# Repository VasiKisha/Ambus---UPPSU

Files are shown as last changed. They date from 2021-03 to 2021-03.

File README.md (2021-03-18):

# Ambus---UPPSU

View this project on [CADLAB.io](https://cadlab.io/project/24060). 

## Ambus Commands
|Command |Description |
|:---:|:---:|
| DEV? | get device description |
| FW? | get firmware version |
| SWITCH?  | get HW switch state |
| MODE? | get CC/CV mode |
| VOLT? | get measured output volrage |
| CURR? | get measured output current |
| SETV(?)  | set(get) output voltage |
| SETC(?)  | set(get) output current |
| SWREM(?) | set(get) remote output control |
| OUTPUT?  | get output relay state |
| CALVG(?) | set(get) calibration voltage gain |
| CALVO(?) | set(get) calibration voltage offset |
| CALIG(?) | set(get) calibration current gain |
| CALIO(?) | set(get) calibration current offset |
| SAVE | save settings to EEPROM |
| LOAD | load settings from EEPROM |

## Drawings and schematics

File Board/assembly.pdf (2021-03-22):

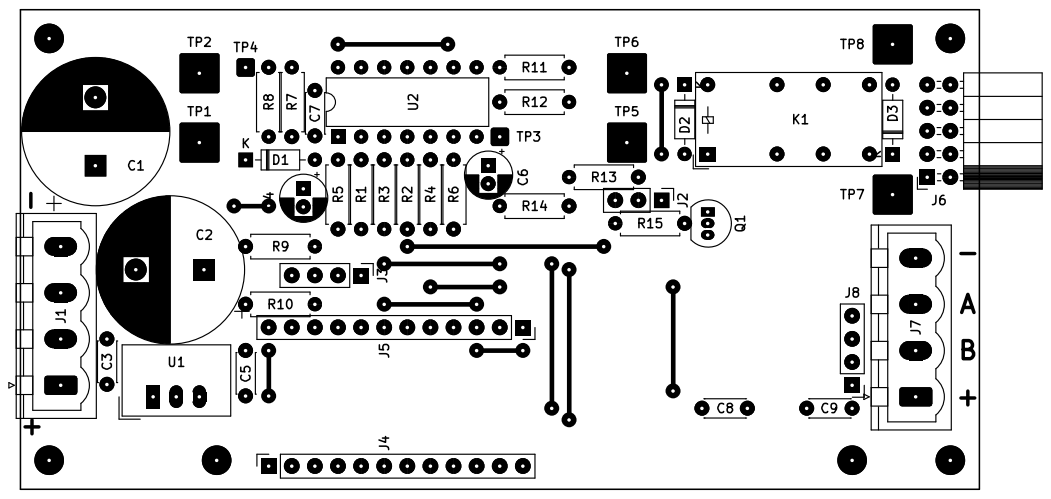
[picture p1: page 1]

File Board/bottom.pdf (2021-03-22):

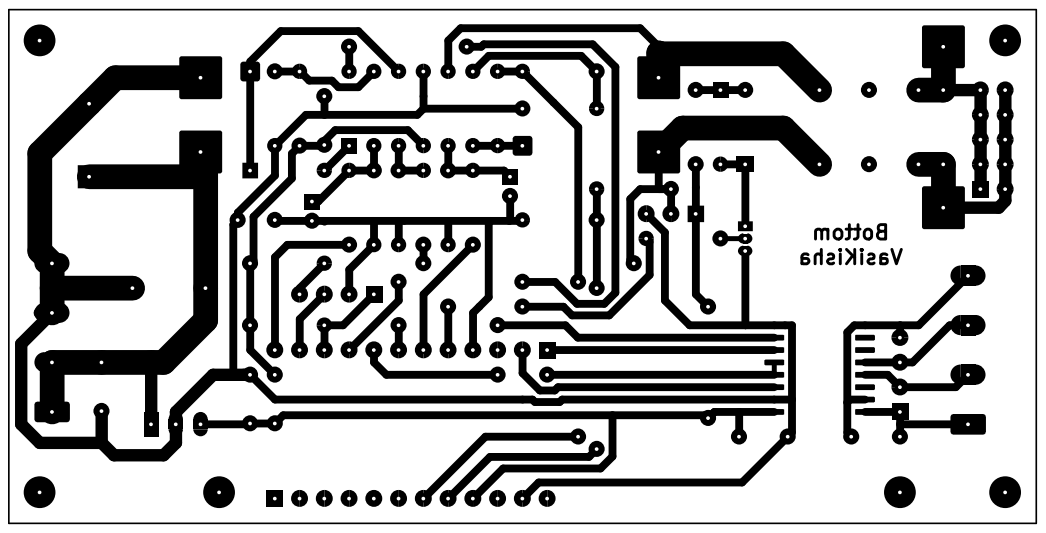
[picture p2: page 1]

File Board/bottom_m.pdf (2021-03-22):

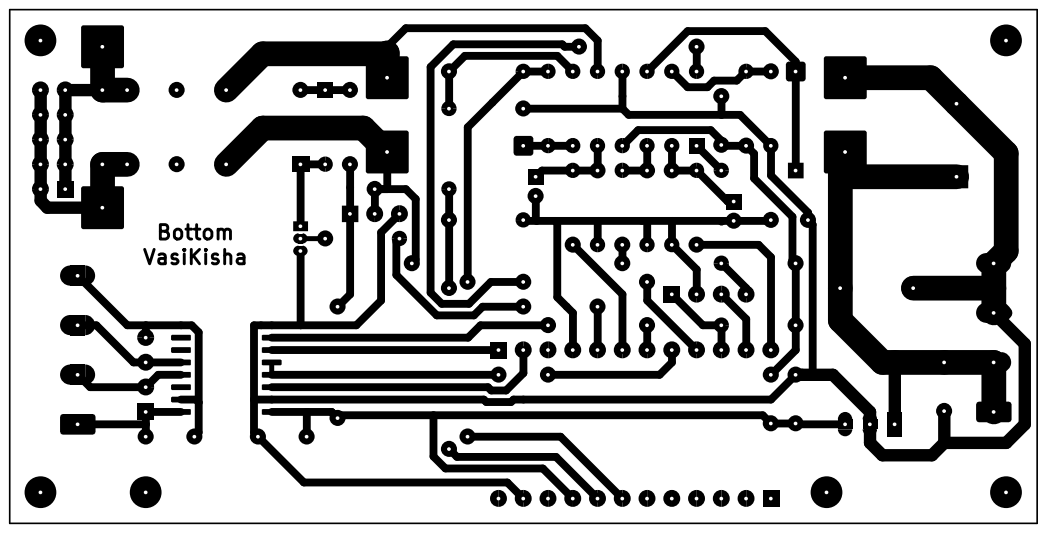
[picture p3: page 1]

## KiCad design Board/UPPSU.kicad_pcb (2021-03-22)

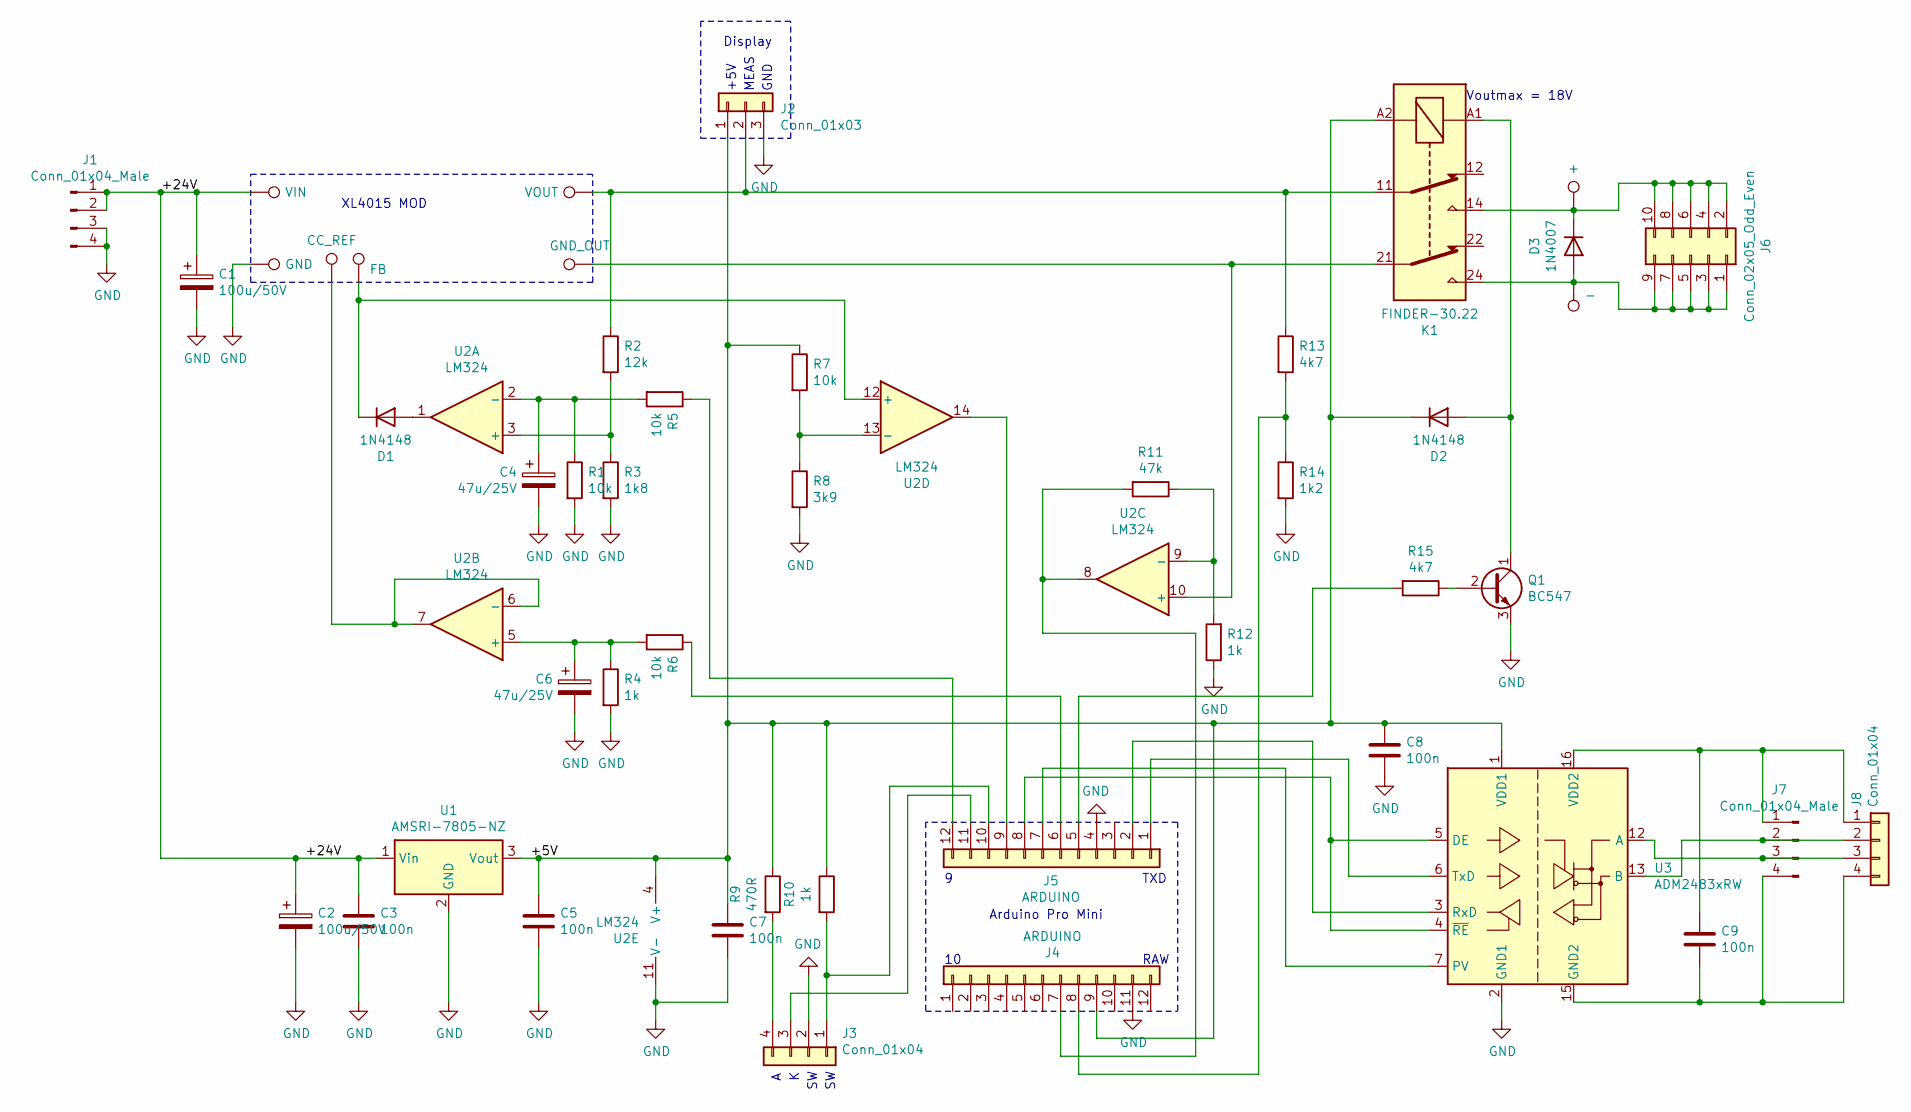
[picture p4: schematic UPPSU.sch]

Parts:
C1, C2: 100u/50V; CP_Radial_D16.0mm_P7.50mm
C3, C5, C7, C8, C9: 100n; C_Disc_D4.3mm_W1.9mm_P5.00mm
C4, C6: 47u/25V; CP_Radial_D5.0mm_P2.00mm
D1, D2: 1N4148; D_DO-35_SOD27_P7.62mm_Horizontal
D3: 1N4007; D_DO-35_SOD27_P7.62mm_Horizontal
J1, J7: Conn_01x04_Male; PhoenixContact_MSTBVA_2,5_4-G-5,08_1x04_P5.08mm_Vertical
J2: Conn_01x03; PinHeader_1x03_P2.54mm_Vertical
J3, J8: Conn_01x04; PinHeader_1x04_P2.54mm_Vertical
J4, J5: ARDUINO; PinSocket_1x12_P2.54mm_Vertical
J6: Conn_02x05_Odd_Even; PinSocket_2x05_P2.54mm_Horizontal
K1: FINDER-30.22; Relay_DPDT_Finder_30.22
Q1: BC547; TO-92_Inline
R1, R5, R6, R7: 10k; R_Axial_DIN0207_L6.3mm_D2.5mm_P7.62mm_Horizontal
R2: 12k; R_Axial_DIN0207_L6.3mm_D2.5mm_P7.62mm_Horizontal
R3: 1k8; R_Axial_DIN0207_L6.3mm_D2.5mm_P7.62mm_Horizontal
R4, R10, R12: 1k; R_Axial_DIN0207_L6.3mm_D2.5mm_P7.62mm_Horizontal
R8: 3k9; R_Axial_DIN0207_L6.3mm_D2.5mm_P7.62mm_Horizontal
R9: 470R; R_Axial_DIN0207_L6.3mm_D2.5mm_P7.62mm_Horizontal
R11: 47k; R_Axial_DIN0207_L6.3mm_D2.5mm_P7.62mm_Horizontal
R13, R15: 4k7; R_Axial_DIN0207_L6.3mm_D2.5mm_P7.62mm_Horizontal
R14: 1k2; R_Axial_DIN0207_L6.3mm_D2.5mm_P7.62mm_Horizontal
TP1: VIN; SolderWire-2.5sqmm_1x01_D2.4mm_OD4.4mm
TP2: GND; SolderWire-2.5sqmm_1x01_D2.4mm_OD4.4mm
TP3: CC_REF; SolderWire-0.25sqmm_1x01_D0.65mm_OD2mm
TP4: FB; SolderWire-0.25sqmm_1x01_D0.65mm_OD2mm
TP5: VOUT; SolderWire-2.5sqmm_1x01_D2.4mm_OD4.4mm
TP6: GND_OUT; SolderWire-2.5sqmm_1x01_D2.4mm_OD4.4mm
TP7: +; SolderWire-2.5sqmm_1x01_D2.4mm_OD4.4mm
TP8: -; SolderWire-2.5sqmm_1x01_D2.4mm_OD4.4mm
U1: AMSRI-7805-NZ; Converter_DCDC_TRACO_TSR-1_THT
U2: LM324; DIP-14_W7.62mm
U3: ADM2483xRW; SOIC-16W_7.5x10.3mm_P1.27mm

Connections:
/+5V: C5.1, C7.1, C8.1, D2.1 (K), J2.1, J4.9, K1.A2, R7.1, R9.1, R10.1, U1.3 (Vout), U2.4 (V+), U3.1 (VDD1)
/+24V: C1.1, C2.1, C3.1, J1.1, J1.2, TP1.1, U1.1 (Vin)
GND: C1.2, C2.2, C3.2, C4.2, C5.2, C6.2, C7.2, C8.2, J1.3, J1.4, J2.3, J3.2, J4.11, J5.4, Q1.3 (E), R1.2, R3.2, R4.2, R8.2, R12.1, R14.2, TP2.1, U1.2 (GND), U2.11 (V-), U3.2 (GND1), U3.8 (GND1)
unnamed: C4.1, R1.1, R5.2, U2.2 (-)
unnamed: C6.1, R4.1, R6.2, U2.5 (+)
unnamed: C9.1, J7.1, J8.1, U3.16 (VDD2)
unnamed: C9.2, J7.4, J8.4, U3.9 (GND2), U3.15 (GND2)
unnamed: D1.1 (K), TP4.1, U2.12 (+)
unnamed: D1.2 (A), U2.1
unnamed: D2.2 (A), K1.A1, Q1.1 (C)
unnamed: D3.1 (K), J6.2, J6.4, J6.6, J6.8, J6.10, K1.14, TP7.1
unnamed: D3.2 (A), J6.1, J6.3, J6.5, J6.7, J6.9, K1.24, TP8.1
unnamed: J2.2, K1.11, R2.1, R13.1, TP5.1
unnamed: J3.1, J5.10, R10.2
unnamed: J3.3, J5.11
unnamed: J3.4, R9.2
unnamed: J4.7, R11.2, U2.8
unnamed: J4.8, R13.2, R14.1
unnamed: J5.1, U3.6 (TxD)
unnamed: J5.2, U3.3 (RxD)
unnamed: J5.5, R15.2
unnamed: J5.6, R6.1
unnamed: J5.7, U3.7 (PV)
unnamed: J5.8, U3.4 (~RE), U3.5 (DE)
unnamed: J5.9, U2.14
unnamed: J5.12, R5.1
unnamed: J7.2, J8.2, U3.13 (B)
unnamed: J7.3, J8.3, U3.12 (A)
unnamed: K1.21, TP6.1, U2.10 (+)
unnamed: Q1.2 (B), R15.1
unnamed: R2.2, R3.1, U2.3 (+)
unnamed: R7.2, R8.1, U2.13 (-)
unnamed: R11.1, R12.2, U2.9 (-)
unnamed: TP3.1, U2.6 (-), U2.7

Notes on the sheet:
XL4015 MOD
Arduino Pro Mini
Display
Voutmax = 18V
RAW
TXD
+5V
MEAS
GND

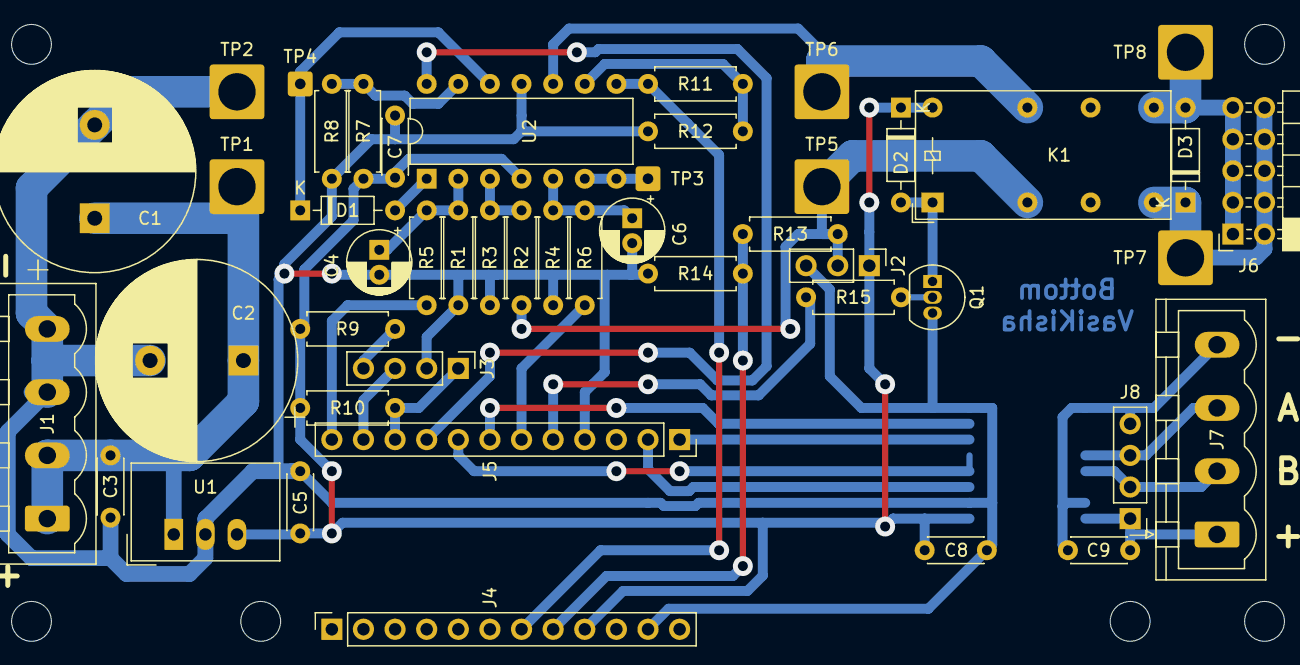
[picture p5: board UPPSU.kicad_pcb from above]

Board: 2 copper layers, 48 parts (1 on the bottom side), 34 nets.

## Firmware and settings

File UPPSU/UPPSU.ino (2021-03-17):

//Copyright (c) 2020 VasiKisha
//All rights reserved.

//This source code is licensed under the MIT-style license found in the
//LICENSE file in the root directory of this source tree. 

//Device description
#define DEVICE "UPPSU"
//Firmware version
#define FIRMWARE "1.0"

//Commands
//DEV?
//FW?
//SWITCH?
//MODE?
//VOLT?
//CURR?
//SETV(?)
//SETC(?)
//SWREM(?)
//OUTPUT?
//CALVG(?)
//CALVO(?)
//CALIG(?)
//CALIO(?)
//SAVE
//LOAD

#include "ambus.h"
#include "EEPROM.h"

#define SWITCH 13   //HW switch
#define LED 12      //LED indicator
#define CCMODE 9    //CC mode = true
#define CVREF 11    //voltage control
#define CCREF 10    //current control
#define VREAD A0    //voltage measure
#define CREAD A1    //current measure

#define MAXVREAD    24.58333    //(Rh = 4k7, Rl = 1k2)
#define MAXCREAD    2.08333     //(Rs = 50mR, A = 48)
#define MAXVSET     19.16666    //(Rh = 12k, Rl = 1k8)
#define MAXCSET     9.09090     //(Rs = 50mR, A = 11)

struct Read
{
    bool switchHW;
    bool switchRem;
    bool ccMode;
    int voltage;
    int current;
};

struct Set
{
    bool led;
    bool output;
    int ccRef;
    int cvRef;
};

struct Timer
{
    int t10;
    int t1000;
    int t300;
};

struct Settings
{
    float vGain;
    int vOffset;
    float iGain;
    int iOffset;
    char myAddress[8];
};

struct Uppsu
{
    Set set;
    Read read;
    Timer timer;
    Settings settings;
}uppsu;

unsigned long previousMillis = 0;

AMBUS ambus("UPPSU", 5);

void setup()
{
    pinMode(CCMODE, INPUT);
    pinMode(SWITCH, INPUT);
    pinMode(LED, OUTPUT);
    pinMode(CVREF, OUTPUT);
    pinMode(CCREF, OUTPUT);
    analogReference(DEFAULT);
    
    EEPROM.get(0, uppsu.settings);
    if (uppsu.settings.myAddress[0] != '\xff') ambus.changeAddress(uppsu.settings.myAddress);
    uppsu.read.switchRem = true;
    Measure();

    Serial.begin(115200);
    uppsu.timer.t10 = 10;
    uppsu.timer.t1000 = 1000;
    uppsu.timer.t300 = 300;
}

void loop()
{
    unsigned long currentMillis = millis();
    if (currentMillis - previousMillis)
    {
        previousMillis = currentMillis;

        if (!uppsu.timer.t300--)
        {
            uppsu.timer.t300 = 300;
            Measure();
            Control();
            
        }

        if (!uppsu.timer.t1000--)
        {

        }       
    }

    if (ambus.dataReceived())
    {
        if (ambus.getCommand() == "DEV?")
        {
            ambus.acknowledge(DEVICE);
        }
        else if (ambus.getCommand() == "FW?")
        {
            ambus.acknowledge(FIRMWARE);
        }
        else if (ambus.getCommand() == "SWITCH?")
        {
            if (uppsu.read.switchHW)
                ambus.acknowledge("ON");
            else
                ambus.acknowledge("OFF");
        }
        else if (ambus.getCommand() == "MODE?")
        {
            if (uppsu.read.ccMode)
                ambus.acknowledge("CC");
            else
                ambus.acknowledge("CV");
        }
        else if (ambus.getCommand() == "VOLT?")
        {
            ambus.acknowledge(String(MAXVREAD * uppsu.read.voltage / 1023.0, 2));
        }
        else if (ambus.getCommand() == "CURR?")
        {
            ambus.acknowledge(String(MAXCREAD * uppsu.read.current / 1023.0, 2));
        }
        else if (ambus.getCommand() == "SETV")
        {
            String temp = ambus.getData();
            uppsu.set.cvRef = 255 * temp.toDouble() / MAXVSET;
            if (uppsu.set.cvRef > 255) uppsu.set.cvRef = 255;
            if (uppsu.set.cvRef < 0) uppsu.set.cvRef = 0;
            ambus.acknowledge(String(MAXVSET * uppsu.set.cvRef / 255, 2));
        }
        else if (ambus.getCommand() == "SETV?")
        {
            ambus.acknowledge(String(MAXVSET * uppsu.set.cvRef / 255, 2));
        }
        else if (ambus.getCommand() == "SETC")
        {
            String temp = ambus.getData();
            uppsu.set.ccRef = 255 * temp.toDouble() / MAXCSET;
            if (uppsu.set.ccRef > 255) uppsu.set.ccRef = 255;
            if (uppsu.set.ccRef < 0) uppsu.set.ccRef = 0;
            ambus.acknowledge(String(MAXCSET * uppsu.set.ccRef / 255, 2));
        }
        else if (ambus.getCommand() == "SETC?")
        {
            ambus.acknowledge(String(MAXCSET * uppsu.set.ccRef / 255, 2));
        }
        else if (ambus.getCommand() == "SWREM")
        {
            String temp = ambus.getData();
            if (temp == "ON")
            {
                uppsu.read.switchRem = true;
                ambus.acknowledge(temp);
            }
            else if (temp == "OFF")
            {
                uppsu.read.switchRem = false;
                ambus.acknowledge(temp);
            }
        }
        else if (ambus.getCommand() == "SWREM?")
        {
            if (uppsu.read.switchRem)
                ambus.acknowledge("ON");
            else
                ambus.acknowledge("OFF");
        }
        else if (ambus.getCommand() == "OUTPUT?")
        {
            if (uppsu.set.output)
                ambus.acknowledge("ON");
            else
                ambus.acknowledge("OFF");
        }
        else if (ambus.getCommand() == "CALVG")
        {
            String temp = ambus.getData();
            uppsu.settings.vGain = temp.toFloat();
            ambus.acknowledge(String(uppsu.settings.vGain, 2));
        }
        else if (ambus.getCommand() == "CALVG?")
        {
            ambus.acknowledge(String(uppsu.settings.vGain, 2));
        }
        else if (ambus.getCommand() == "CALVO")
        {
            String temp = ambus.getData();
            uppsu.settings.vOffset = temp.toInt();
            ambus.acknowledge(String(uppsu.settings.vOffset));
        }
        else if (ambus.getCommand() == "CALVO?")
        {
            ambus.acknowledge(String(uppsu.settings.vOffset));
        }
        else if (ambus.getCommand() == "CALIG")
        {
            String temp = ambus.getData();
            uppsu.settings.iGain = temp.toFloat();
            ambus.acknowledge(String(uppsu.settings.iGain, 2));
        }
        else if (ambus.getCommand() == "CALIG?")
        {
            ambus.acknowledge(String(uppsu.settings.iGain, 2));
        }
        else if (ambus.getCommand() == "CALIO")
        {
            String temp = ambus.getData();
            uppsu.settings.iOffset = temp.toInt();
            ambus.acknowledge(String(uppsu.settings.iOffset));
        }
        else if (ambus.getCommand() == "CALIO?")
        {
            ambus.acknowledge(String(uppsu.settings.iOffset));
        }
        else if (ambus.getCommand() == "SAVE")
        {
            strcpy(uppsu.settings.myAddress, ambus.myAddress().c_str());
            EEPROM.put(0, uppsu.settings);
            ambus.acknowledge("EEPROM Saved");
        }
        else if (ambus.getCommand() == "LOAD")
        {
            EEPROM.get(0, uppsu.settings);
            ambus.changeAddress(uppsu.settings.myAddress);
            ambus.acknowledge("EEPROM Loaded");
        }
    }
}

void Measure()
{
    uppsu.read.switchHW = digitalRead(SWITCH);
    uppsu.read.ccMode = digitalRead(CCMODE);
    uppsu.read.voltage = analogRead(VREAD);
    uppsu.read.current = analogRead(CREAD);
}

void Control()
{
    if (uppsu.read.switchHW && uppsu.read.switchRem)
    {
        uppsu.set.output = true;
        uppsu.set.led = true;
    }
    else
    {
        uppsu.set.output = false;
        uppsu.set.led = false;
    }

    if (uppsu.set.led) digitalWrite(LED, HIGH);
    else digitalWrite(LED, LOW);

    int calValue = uppsu.settings.vOffset + (int)(uppsu.set.cvRef * uppsu.settings.vGain);
    if (calValue > 255) calValue = 255;
    analogWrite(CVREF, calValue );
    calValue = uppsu.settings.iOffset + (int)(uppsu.set.ccRef * uppsu.settings.iGain);
    if (calValue > 255) calValue = 255;
    analogWrite(CCREF, calValue);
}

void serialEvent()
{
    ambus.serialEventHandler();
}

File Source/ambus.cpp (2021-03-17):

//Copyright (c) 2020 VasiKisha
//All rights reserved.

//This source code is licensed under the MIT-style license found in the
//LICENSE file in the root directory of this source tree. 

/*
 * ambus.cpp
 *
 * Created: 02.07.2016 9:13:05
 * Author: VasiKisha
 */

#include <Arduino.h>
#include "ambus.h"

//#define AMBUS_DEBUG

//PACKET DEFINITIONS
#define START_OF_PACKET '$'
#define SEPARATOR       ';'
#define END_OF_PACKET   '\n'
#define ADDRESS_SIZE    8
#define COMMAND_SIZE    8
#define DATA_SIZE       32
#define CRC_SIZE        1
#define PACKET_SIZE     ADDRESS_SIZE + COMMAND_SIZE + DATA_SIZE + CRC_SIZE + 5

AMBUS::AMBUS(String myAddress, int setDirectionPin)
{
    dataPacket.reserve(PACKET_SIZE);
    address.reserve(ADDRESS_SIZE);
    command.reserve(COMMAND_SIZE);
    data.reserve(DATA_SIZE);
    crc.reserve(CRC_SIZE);

    directionPin = setDirectionPin;
    pinMode(directionPin, OUTPUT);
    digitalWrite(directionPin, LOW);

    deviceAddress = myAddress;
    broadcast = "AMBUS";
    dataPacket = "";
    address = "";
    command = "";
    data = "";
    crc = "";

    receiving = false;
    dataReady = false;
}

bool AMBUS::changeAddress(String myAddress)
{
    if (myAddress.length() > 0 && myAddress.length() <= ADDRESS_SIZE)
    {
        for (int i = 0; i < myAddress.length(); i++)
        {
            if (myAddress[i] == START_OF_PACKET) return false;
            if (myAddress[i] == SEPARATOR) return false;
            if (myAddress[i] == END_OF_PACKET) return false;
        }
        deviceAddress = myAddress;
        return true;
    }
    else return false;
}

String AMBUS::myAddress()
{
    return deviceAddress;
}

void AMBUS::serialEventHandler()
{
    //if no data ready, skip
    if (dataReady == true) return;

    //read character 
    char inChar = (char)Serial.read();

    //not in receiving mode yet, waiting gor start of packet
    if (receiving == false)
    {
        if (inChar == START_OF_PACKET)
        {
            receiving = true;
            dataPacket = "";
            dataPacket += inChar;
            return;
        }
    }

    //receiving mode
    else
    {
        if (inChar == START_OF_PACKET) //new SOP detected
        {
            dataPacket = "";
        }
        dataPacket += inChar;
        if (dataPacket.length() >= PACKET_SIZE) //message is too long
        {
            receiving = false;
            return;
        }
        if (inChar == END_OF_PACKET)    //EOP detected
        {
            stringParser();    //message parser
            if (crc[0] != checksum(dataPacket, dataPacket.length() - 1 - CRC_SIZE)) //checksum check
            {
#ifdef AMBUS_DEBUG
                Serial.print("CRC NOT MATCH: ");
                Serial.println(checksum(dataPacket, dataPacket.length() - (1 + CRC_SIZE)));
#endif
                command = "ERROR";  
                String crcsum = "CRC NOT MATCH:  ";
                crcsum[15] = checksum(dataPacket, dataPacket.length() - (1 + CRC_SIZE));
                acknowledge(crcsum);
                address = "";
                command = "";
                data = "";
                crc = "";
                receiving = false;
                return;
            }
            else if (address == broadcast)
            {
                if (command == "ADDRESS?")
                {
                    acknowledge(deviceAddress);
                    address = "";
                    command = "";
                    data = "";
                    crc = "";
                    receiving = false;
                    return;
                }
                else if (command == "ADDRESS")
                {
                    if (changeAddress(data)) acknowledge(deviceAddress);
                    address = "";
                    command = "";
                    data = "";
                    crc = "";
                    receiving = false;
                    return;
                }
            }
            else if (address != deviceAddress)    //address check
            {
#ifdef AMBUS_DEBUG
                Serial.println("ADDRESS NOT MATCH: ");
                Serial.println(address);
#endif
                //command = "ERROR";
                //acknowledge("ADDRESS NOT MATCH: " + address);
                address = "";
                command = "";
                data = "";
                crc = "";
                receiving = false;
                return;
            }

            dataReady = true;    //message is correct and ready to pickup
            receiving = false;
        }
    }
}

boolean AMBUS::dataReceived()
{
    return dataReady;
}

String AMBUS::getCommand()
{
    return command;
}

String AMBUS::getData()
{
    return data;
}

void AMBUS::notacknowledge()
{
#ifdef AMBUS_DEBUG
    Serial.println("NACK");
#endif
    address = "";
    command = "";
    data = "";
    crc = "";
    dataReady = false;
}

void AMBUS::acknowledge(String answer)
{
    dataPacket = START_OF_PACKET;
    dataPacket += deviceAddress;
    dataPacket += SEPARATOR;
    dataPacket += command;
    dataPacket += SEPARATOR;
    dataPacket += answer;
    if (answer != "") dataPacket += SEPARATOR;
    dataPacket += checksum(dataPacket, dataPacket.length());
    dataPacket += END_OF_PACKET;
    //delay(4); // na RX vysí po skonèení pøijmu nìjak moc dlouho HIGH...
    digitalWrite(directionPin, HIGH);;
    Serial.print(dataPacket);
    Serial.flush();
    digitalWrite(directionPin, LOW);
    address = "";
    command = "";
    data = "";
    crc = "";
    dataReady = false;
}

void AMBUS::stringParser()
{
    unsigned int separatorCounter = 0;
    unsigned int i = 1;
    unsigned int j = 0;

    while (dataPacket[i] != END_OF_PACKET)
    {
        if (dataPacket[i] == SEPARATOR)
        {
            separatorCounter++;
            i++;
            j = 0;
            continue;
        }

        switch (separatorCounter)
        {
        case 0:        //address
            if (j >= ADDRESS_SIZE) break;
            address += dataPacket[i];
            break;

        case 1:        //command
            if (j >= COMMAND_SIZE) break;
            command += dataPacket[i];
            break;

        case 2:        //data
            if (j >= DATA_SIZE) break;
            data += dataPacket[i];
            break;

        case 3:        //crc
            if (j >= CRC_SIZE) break;
            crc += dataPacket[i];
            break;

        default:
            break;
        }

        i++;
        j++;
    }

    //if message doesn't contain DATA
    if (separatorCounter == 2)
    {
        crc = data;
        data = "";
    }
}

char AMBUS::checksum(String data, unsigned int count)
{
    int sum = 0;
    for (unsigned int i = 0; i < count; i++)
    {
        sum = (sum + data[i]) % 255;
    }
    if ((char)sum == START_OF_PACKET || (char)sum == SEPARATOR || (char)sum == END_OF_PACKET)
    {
        sum += 0x80;
    }
    return (char)sum;
}

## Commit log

2021-03-17 Ability to change/read address via broadcast, ack with device address, not MASTER
2021-03-18 Edited folder structure
    [UPPSU.sch]
2021-03-18 Initial release
    [UPPSU.sch]
2021-03-22 Board update
    [UPPSU.kicad_pcb, UPPSU.sch]
